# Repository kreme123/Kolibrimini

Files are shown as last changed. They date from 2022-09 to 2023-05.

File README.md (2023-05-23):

# Kolibrimini
Kolibrimini is 40% Alice-style keyboard with arrow cluster
- Uses Pro Micro 
- Plateless
- Pcb isolated from case using rubber plugs and o-rings
- MJF printed case (JLCPCB)
- Rgb underglow

- ### Pics
<a href="https://imgur.com/M5Mwt2X">source: imgur.com</a>
<a href="https://imgur.com/hWzJRXO">source: imgur.com</a>
<a href="https://imgur.com/mCCqhqe">source: imgur.com</a>

[Soundtest](https://www.youtube.com/watch?v=7RpJeCfO46M) 

(https://www.paypal.com/donate/?hosted_button_id=BAEE2KMJAVYBW)

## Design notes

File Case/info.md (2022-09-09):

Case is MJF printed, ordered from JLCPCB. There's little bit of shrink from 3d printing so be aware of that.

Backplate is lasercutted from 3mm thick acrylic.

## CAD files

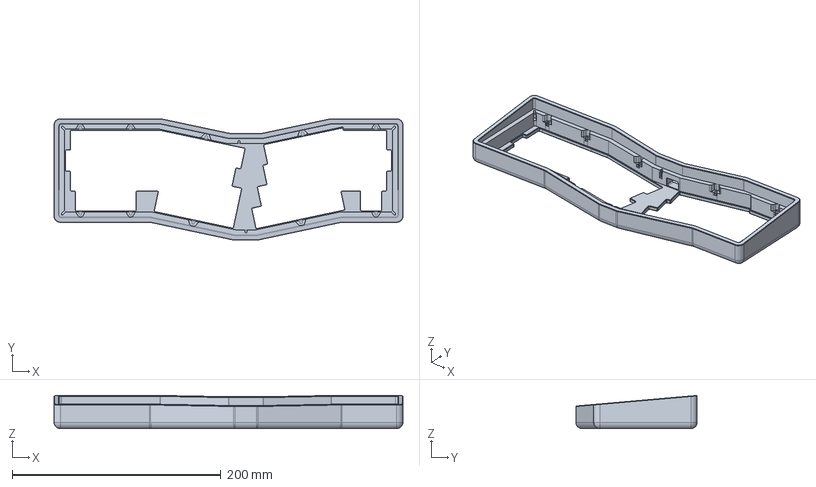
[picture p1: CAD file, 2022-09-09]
Case/3DPrint/kolibriminiMJF.step
334.2 x 116.3 x 31.7 mm

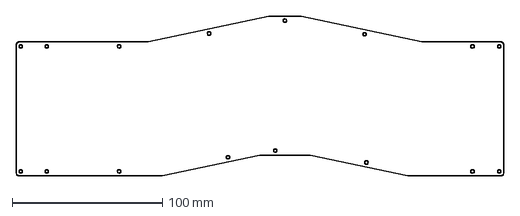
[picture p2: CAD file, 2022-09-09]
Case/Acrylic backplate (3mm)/Kolibrimini bottom plate (3mm).dxf
324.2 x 106.3 mm

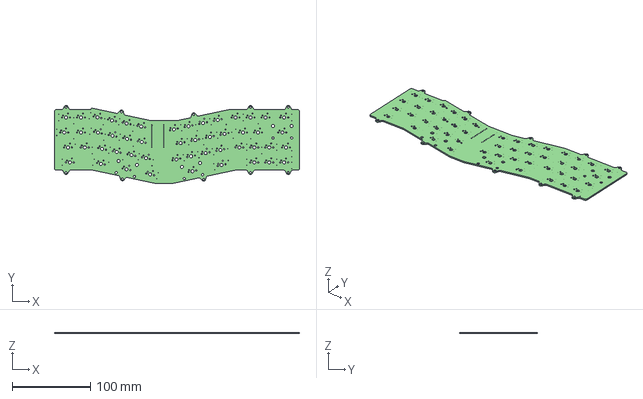
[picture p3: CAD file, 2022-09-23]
kolibriminirev01step.step
312.2 x 99.8 x 1.60 mm

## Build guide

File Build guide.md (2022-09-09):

# Build guide
<a href="https://imgur.com/mUwVn8U">source: imgur.com</a>
## Materials
- 6 x [M2x8mm screws](https://www.aliexpress.com/item/1005002946010479.html)
- 10  x [M2x6mm screws](https://www.aliexpress.com/item/1005002946010479.html)
- 6 x [M2x6mm (OD3.2mm) insert](https://www.aliexpress.com/item/1005003582355741.html)
- 10 x [M2x3mm (OD3.2mm) insert](https://www.aliexpress.com/item/1005003582355741.html)
- ~50 [1N4148 SOD-123 Diode](https://www.aliexpress.com/item/1005002383505485.html)
- 10 x [2.5mm Rubber Plug](https://www.aliexpress.com/item/1005002952659495.html)
- 10 x [ID 3mm OD 6mm, CS 1.5mm O-rings](https://www.aliexpress.com/item/1005003221523684.html)
- 4 x [20x4x1.5mm Silicone rubber feet](https://www.aliexpress.com/item/1005002019084238.html)
- 14 x [WS2812B 5050 RGB LED](https://www.aliexpress.com/item/1005002653014067.html) 
- [Pro Micro TYPE-C USB 3-6V](https://www.aliexpress.com/item/32840365436.html) Check right model, bigger one won't fit nicely.

### Also
- Soldering iron and solder
- Hex screwdriver
- Flush side cutters
- ~50 MX style switches
- 3 x 2u PCB mount stabilizers
- Keycaps (check compatibility)

## Building

Connect Pro Micro to computer and flash "kolibrimini_default.hex" firmware using qmk toolbox
<a href="https://imgur.com/jdxeeJ3">source: imgur.com</a>

Pcb
<a href="https://imgur.com/GFyuosE">source: imgur.com</a>

Solder diodes for all keys. Stripe on diode to square pad on pcb

For rgb leds !!Check that led is correct way!! (triangle goes top left). 
<a href="https://imgur.com/G3XKEeZ">source: imgur.com</a>

Solder Pro Micro to top side of pcb. Check that pins match.
<a href="https://imgur.com/9bmE7ds">source: imgur.com</a>

Now it's good time to test pcb. Connect it to your computer and use tweezers to test keys.

Solder switches and add stabilizers. Add rubber plugs from bottom of pcb. 

Use something like small screwdriver or tweezers to get rubber plugs through hole. Now you can place O-rings to top.
<a href="https://imgur.com/9smIp5p">source: imgur.com</a>

MJF printed case
<a href="https://imgur.com/quPCpGK">source: imgur.com</a>
<a href="https://imgur.com/SeeLkav">source: imgur.com</a>

Place 6 x 6mm brass inserts to case. I had to use alot of force to get them there. Hole size of the model is fine, but there was some shrink from printing.
<a href="https://imgur.com/0xxMzxT">source: imgur.com</a>

Acrylic (3mm) backplate
<a href="https://imgur.com/QSLOKZ1">source: imgur.com</a>

Place 10 x 6mm screws from bottom of backplate. Then add 3mm brass inserts.
<a href="https://imgur.com/ZTMi4dN">source: imgur.com</a>

Time to assemble
<a href="https://imgur.com/gEtkeDp">source: imgur.com</a>
<a href="https://imgur.com/Vp9g273">source: imgur.com</a>
<a href="https://imgur.com/eu9mu90">source: imgur.com</a>
<a href="https://imgur.com/zcP5Mh0">source: imgur.com</a>
<a href="https://imgur.com/rErGkdw">source: imgur.com</a>

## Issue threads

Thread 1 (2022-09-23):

Step file for PCB

Nirzhuk, 2022-09-23:
Hello,

If you can release the step file for the PCB because I want to develop an acrylic case for this keyboard.
Thanks!

kreme123, 2022-09-23:
Step file for PCB added

Nirzhuk, 2022-09-25:
Thanks!

Nirzhuk, 2022-09-25:
@kreme123 I might need the plate too because I'm doing some type of gasket with acrylic :P

Closed 2022-09-25.

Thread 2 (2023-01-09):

Hello,I want to know what the material of the shell is in the picture，thanks！

NiKoscar, 2023-01-09:
The shell texture in the picture is very good

kreme123, 2023-01-09:
Material of the shell is nylon. It is MJF (multi jet fusion) 3d printed and I've ordered it from JLCPCB.

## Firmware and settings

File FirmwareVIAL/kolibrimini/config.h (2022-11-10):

// Copyright 2022 kreme
// SPDX-License-Identifier: GPL-2.0-or-later

#pragma once

#include "config_common.h"

/* USB Device descriptor parameter */
#define VENDOR_ID       0xFEED
#define PRODUCT_ID      0x0000
#define DEVICE_VER      0x0001
#define MANUFACTURER    kreme
#define PRODUCT         kolibrimini

/* key matrix size */
#define MATRIX_ROWS 7
#define MATRIX_COLS 8

/*
 * Keyboard Matrix Assignments
 *
 * Change this to how you wired your keyboard
 * COLS: AVR pins used for columns, left to right
 * ROWS: AVR pins used for rows, top to bottom
 * DIODE_DIRECTION: COL2ROW = COL = Anode (+), ROW = Cathode (-, marked on diode)
 *                  ROW2COL = ROW = Anode (+), COL = Cathode (-, marked on diode)
 *
 */
#define MATRIX_ROW_PINS { D2, D0, D7, D4, D3, D1, C6 }
#define MATRIX_COL_PINS { B5, B4, E6, F7, B1, B3, B2, B6 }

#define DIODE_DIRECTION COL2ROW

// reduce memory
#undef LOCKING_SUPPORT_ENABLE
#undef LOCKING_RESYNC_ENABLE
#define NO_ACTION_ONESHOT
#define LAYER_STATE_8BIT

#define RGB_DI_PIN F6
#ifdef RGB_DI_PIN
#define RGBLED_NUM 14
#define RGBLIGHT_HUE_STEP 8
#define RGBLIGHT_SAT_STEP 8
#define RGBLIGHT_VAL_STEP 8
#define RGBLIGHT_LIMIT_VAL 255 /* The maximum brightness level */
#define RGBLIGHT_SLEEP  /* If defined, the RGB lighting will be switched off when the host goes to sleep */
 /*== all animations enable ==*/
// /*== or choose animations ==*/
     #define RGBLIGHT_EFFECT_BREATHING
     #define RGBLIGHT_EFFECT_RAINBOW_MOOD
     #define RGBLIGHT_EFFECT_RAINBOW_SWIRL
     #define RGBLIGHT_EFFECT_SNAKE
     #define RGBLIGHT_EFFECT_KNIGHT
     #define RGBLIGHT_EFFECT_CHRISTMAS
     #define RGBLIGHT_EFFECT_STATIC_GRADIENT
     #define RGBLIGHT_EFFECT_RGB_TEST
     #define RGBLIGHT_EFFECT_ALTERNATING
#endif

// generated by KBFirmware JSON to QMK Parser
// https://noroadsleft.github.io/kbf_qmk_converter/
